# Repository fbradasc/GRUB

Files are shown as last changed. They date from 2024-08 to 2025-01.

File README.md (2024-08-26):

# GRUB

```
                          G-R-U-B
                          | | | |
                          | | | +----> <B>lue  (440nm) - Royal blue
                          | | +------> <U>V    (425nm) - Near Violet
                          | +--------> <R>ed   (660nm) - Deep red
                          +----------> <G>reen (525nm)
```

**GRUB** is a LEDs control board for an enlarger variable contrast & color head
GRUB main schematic
GRUB power rack schematic
GRUB drivers schematic
GRUB metronome schematic

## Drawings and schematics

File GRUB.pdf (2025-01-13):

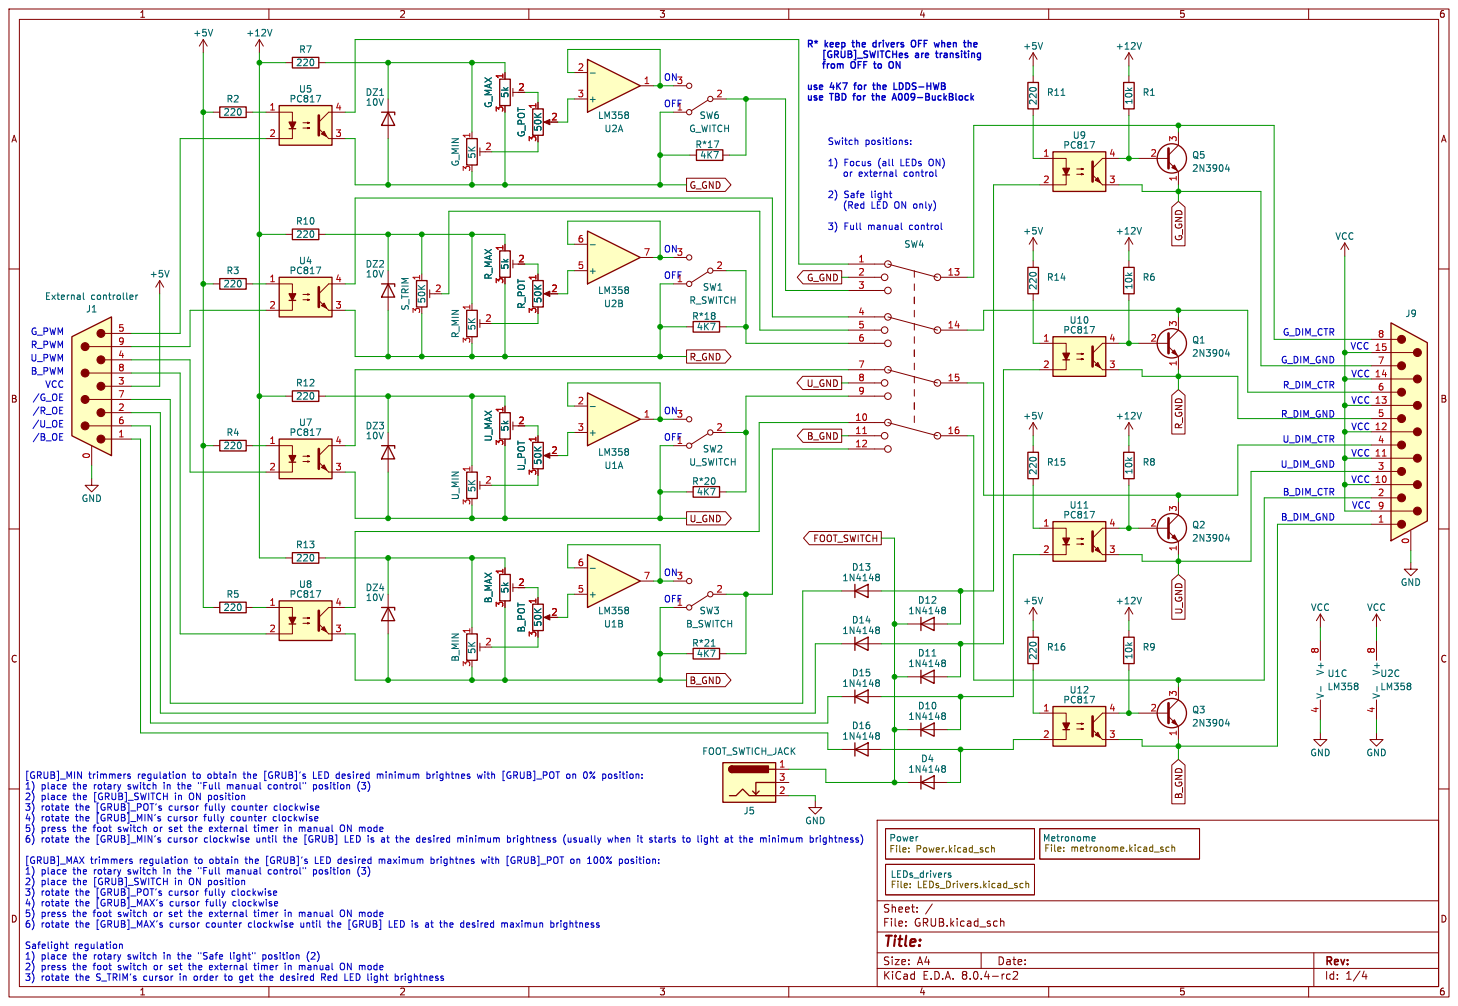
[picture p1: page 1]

3) Full manual control R* keep the drivers OFF when the
[GRUB]_SWITCHes are transiting
from OFF to ON

use 4K7 for the LDDS-HWB

(Red LED ON only)

2) place the [GRUB]_SWITCH in ON position
3) rotate the [GRUB]_POT's cursor fully counter clockwise
4) rotate the [GRUB]_MIN's cursor fully counter clockwise

3) rotate the [GRUB]_POT's cursor fully clockwise
4) rotate the [GRUB]_MAX's cursor fully clockwise

3) rotate the S_TRIM's cursor in order to get the desired Red LED light brightness

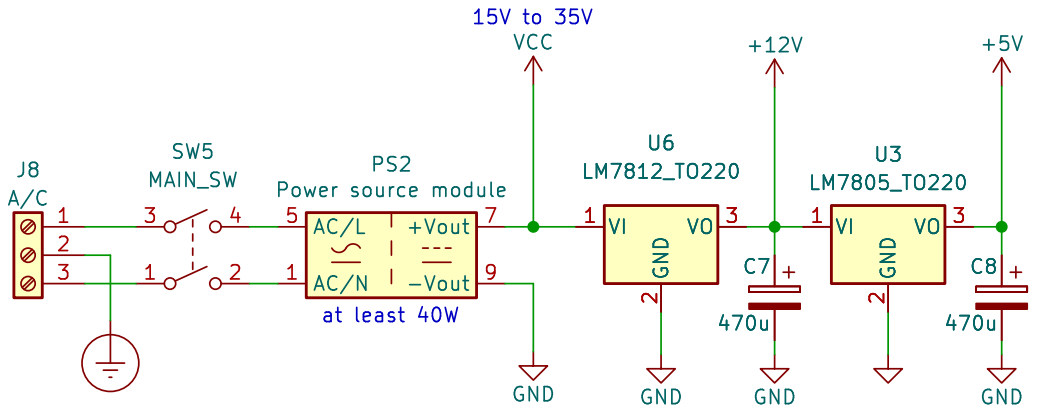
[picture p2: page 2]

Id: 2/4 Title: File: Power.kicad_sch Sheet: /Power/

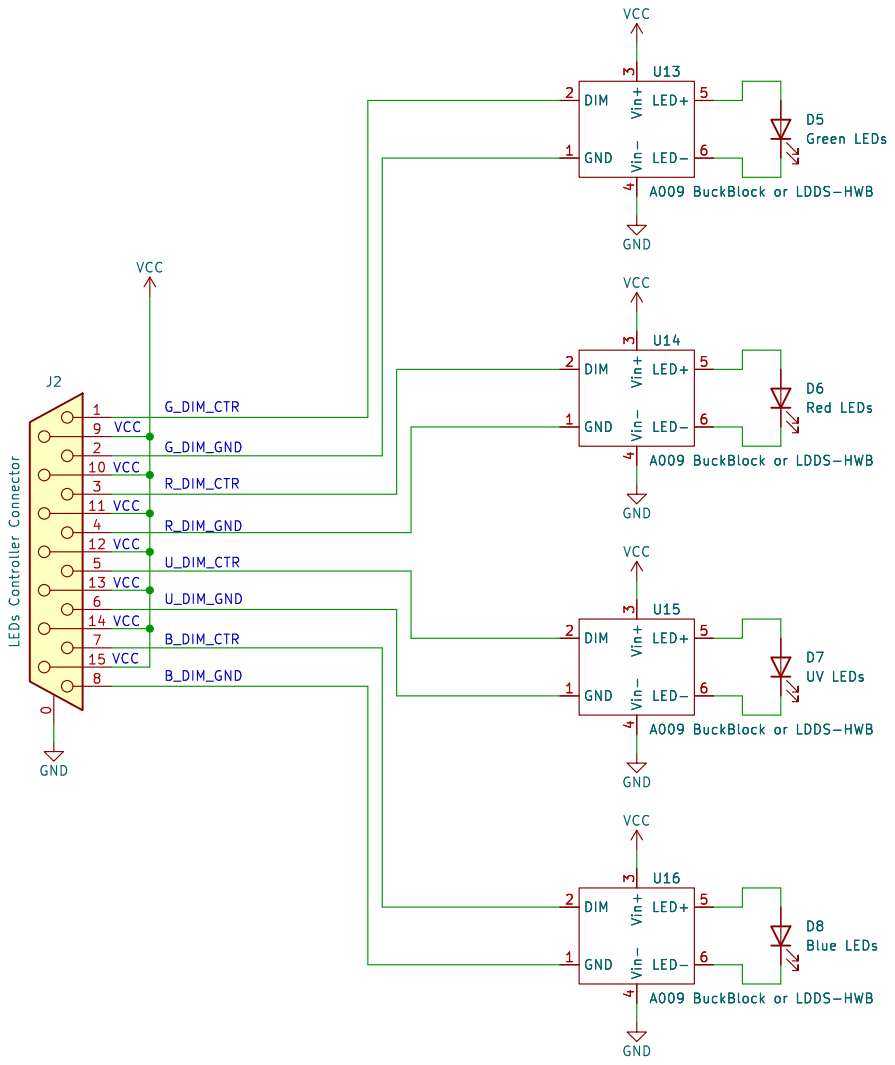
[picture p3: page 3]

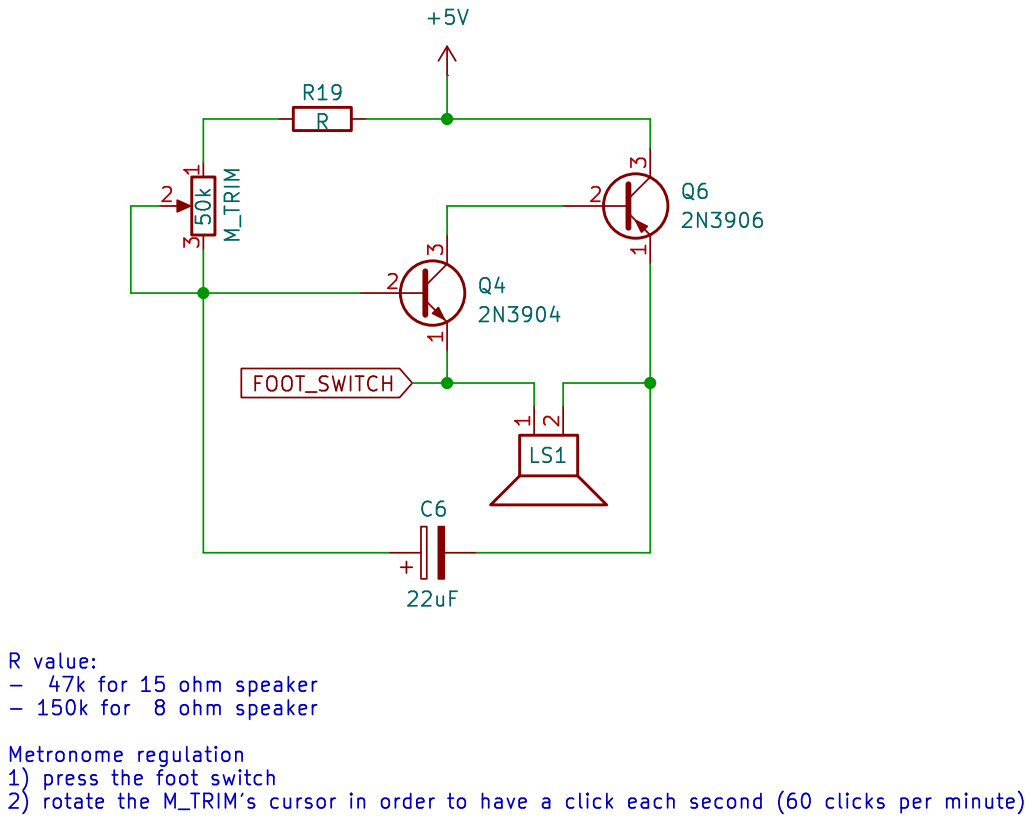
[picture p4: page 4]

1) press the foot switch
2) rotate the M_TRIM's cursor in order to have a click each second (60 clicks per minute)

Id: 4/4 Title: File: metronome.kicad_sch Sheet: /Metronome/

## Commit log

2024-03-18 Adding optocoupler for external controls
    [GRUB.kicad_pcb, GRUB.kicad_sch, LEH.kicad_sch]
2024-03-18 Adding schematic image
2024-03-18 Adding link to A009 datasheet
    [GRUB.kicad_sch]
2024-04-03 Adding option for LDDS-HWB LED driver
    [GRUB.kicad_sch]
2024-04-04 Changed the DIM control from potentiometer mode to voltage mode, added trimmers regulations description
    [GRUB.kicad_sch]
2024-04-04 Given the proper names to the LEDs activation switches
    [GRUB.kicad_sch]
2024-04-09 Using single PC817 optocoupler instead of cumulative PC847
    [GRUB.kicad_sch]
2024-04-10 Safe light regulated by voltage, not by resistor
    [GRUB.kicad_sch]
2024-04-11 Adding connectors and separate power lines
    [GRUB.kicad_sch, LEDs_Drivers.kicad_sch]
2024-04-11 Renamed GRUB-LEDs drivers.svg -> GRUB-LEDs_drivers.svg
2024-04-12 Adding power rack schematic
    [GRUB.kicad_sch, Power.kicad_sch]
2024-05-28 Fix typo
    [GRUB.kicad_sch]
2024-06-04 Using two LM317s instead of a LM7812 + LM7805
    [Power.kicad_sch]
2024-06-06 KiCAD 8.0.3
    [GRUB.kicad_sch, LEDs_Drivers.kicad_sch, Power.kicad_sch]
2024-06-07 Using two LM317s instead of a LM7812 + LM7805 and KiCAD 8.0.3rc1
    [GRUB.kicad_sch, LEDs_Drivers.kicad_sch, Power.kicad_sch]
2024-07-12 - Power rack alternatives: either two LM317s or LM7812 + LM7805 - Added channels SPDT selectors for foot switch or external output enable control
    [GRUB.kicad_sch, LEDs_Drivers.kicad_sch, Power.kicad_sch]
2024-07-16 Adding metronome commanded by foot switch
    [Foot_Switch.kicad_sch, GRUB.kicad_sch, metronome.kicad_sch]
2024-07-18 Fix metronome R and C values to allow frequency down to 1 Hz
    [metronome.kicad_sch]
2024-07-22 Show a couple of R values in metronome circuit depending on speaker resistance
    [GRUB.kicad_sch, metronome.kicad_sch]
2024-08-26 Adding capacitors to stabilize voltages, changed the LED driver connector
    [GRUB.kicad_sch, LEDs_Drivers.kicad_sch, Power.kicad_sch]
2024-08-26 Changed the power witch
    [Power.kicad_sch]
2024-08-26 Adding PDF with full schematics
2025-01-13 - Adding pulldown resistors to keep LEDs drivers OFF when [GRUB]_SWITCHes transits from OFF to ON - Adding op-amps as voltage follower between [GRUB]_POTs and [GRUB]_SWITCHes to guarantee linearity i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
    [GRUB.kicad_sch]
2025-01-13 Updating SVG and PDF schematics
